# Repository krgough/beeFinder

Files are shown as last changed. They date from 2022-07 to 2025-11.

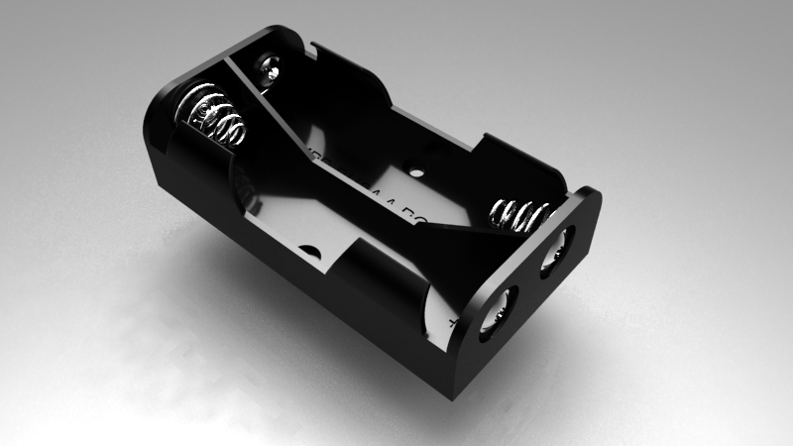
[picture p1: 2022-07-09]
docs/aa-battery-holder-2.snapshot.6/Renderings/aa holder.jpg

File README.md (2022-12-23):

# beeFinder

This device consists of:
- An array of 5x5 LEDs used as a display
- An RFM69HW 868MHz radio
- Arduino Pro Mini used as the controller

We have 2 modes of operation:
1) Display Name of Owner - Name scrolls from left to right.
2) Transmit a broadcast to other devices on 868MHz network.  Each column of LEDs is a user and the column leds correspond to the RSSI for that device.  The column for this device has only the lower LED lit

Mode selection is done using the SCAN/NAME switch.

# config.h
Create a config.h file with the radio encryption key.  This must be exactly 16 chars e.g.
```
#define ENCRYPTKEY    "sampleEncryptKey"
```

# vs-code
Install the arduino extension
Install arduino-cli
```
brew install arduino-cli
```
*** IMPORTANT: Restart vs-code

Use ```which arduino-cli``` to find the location of your executable
Set these vs-code settings...
arduino.path = <folder from 'which arduino-cli'>
arduino.command_path = arduino-cli

Set the script name in ardiono.json  

Typical arduino.json:
```
{
    "port": "/dev/tty.usbserial-AQ034BWC",
    "configuration": "cpu=16MHzatmega328",
    "board": "arduino:avr:pro",
    "sketch": "bee_finder_firmware/bee_finder/bee_finder.ino"
}
```

# Programming
- Connect GND, Tx, Rx
- Connect RTS from FTDI cable to DTR on the beekeeper device to allow it to set programming mode

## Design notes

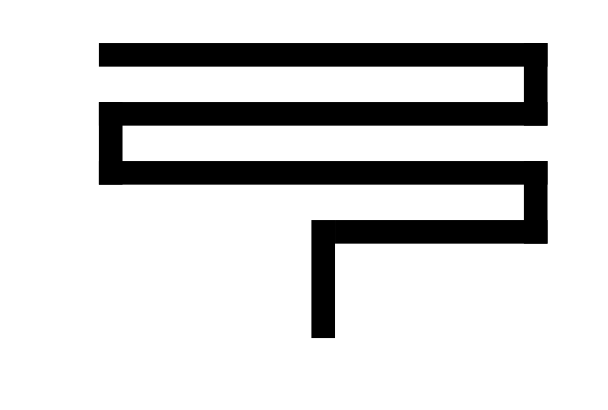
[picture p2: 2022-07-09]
docs/antenna/ti-868-antenna-meander.png

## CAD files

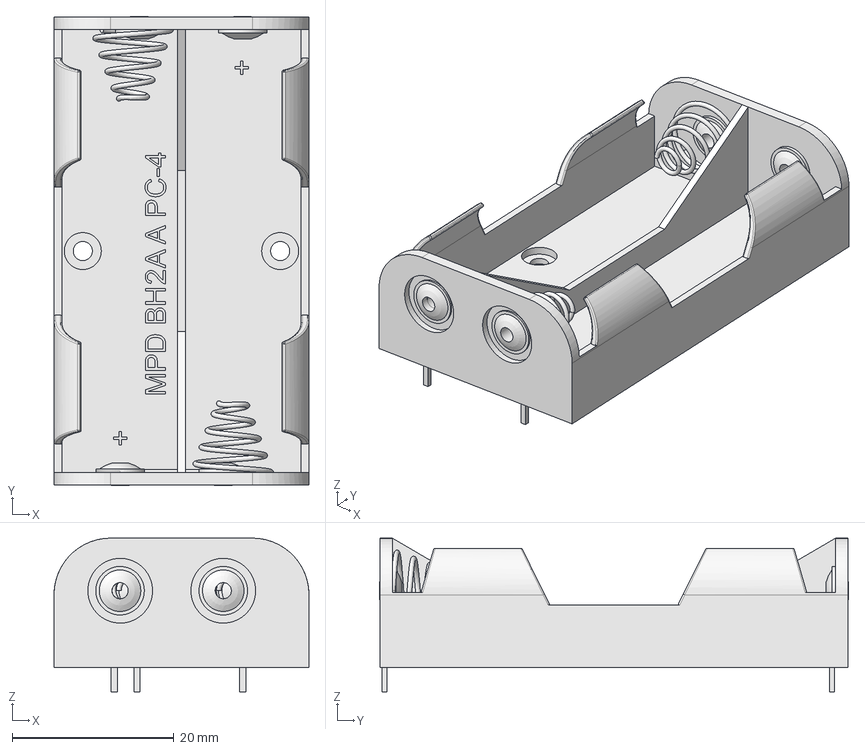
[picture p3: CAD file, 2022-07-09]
docs/aa-battery-holder-2.snapshot.6/aa_battery_box_pcb.step
31.5 x 58.0 x 19.0 mm

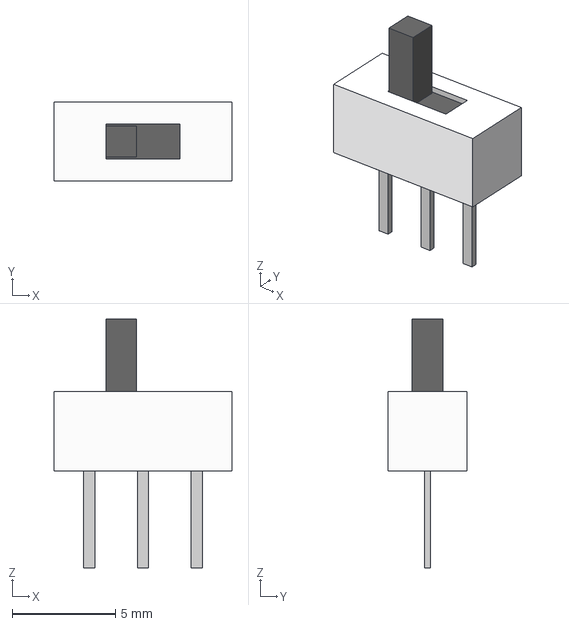
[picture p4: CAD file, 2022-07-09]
docs/Switch_SS12D00G4/SS12D00G4 1P2T Straight.step
8.61 x 3.85 x 12.1 mm

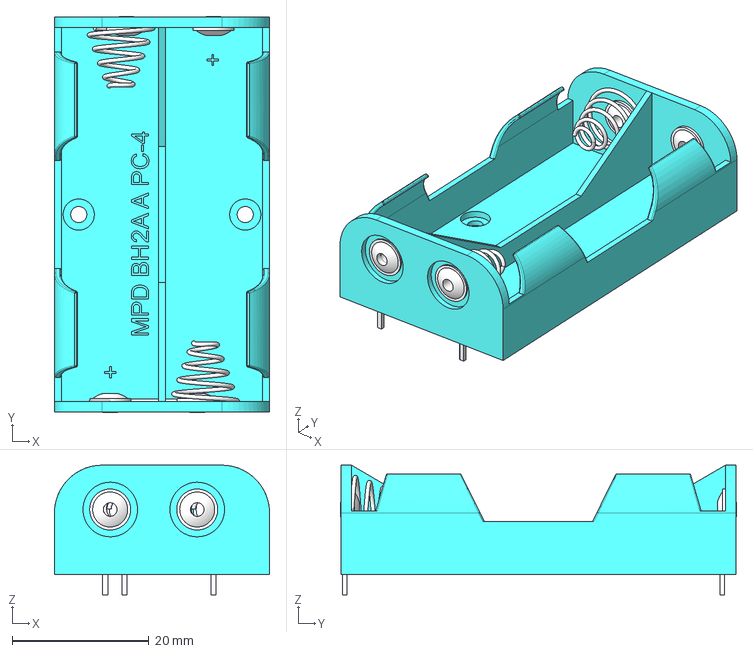
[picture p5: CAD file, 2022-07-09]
docs/aa-battery-holder-2.snapshot.6/AABattery Holder.stp
31.5 x 58.0 x 19.0 mm

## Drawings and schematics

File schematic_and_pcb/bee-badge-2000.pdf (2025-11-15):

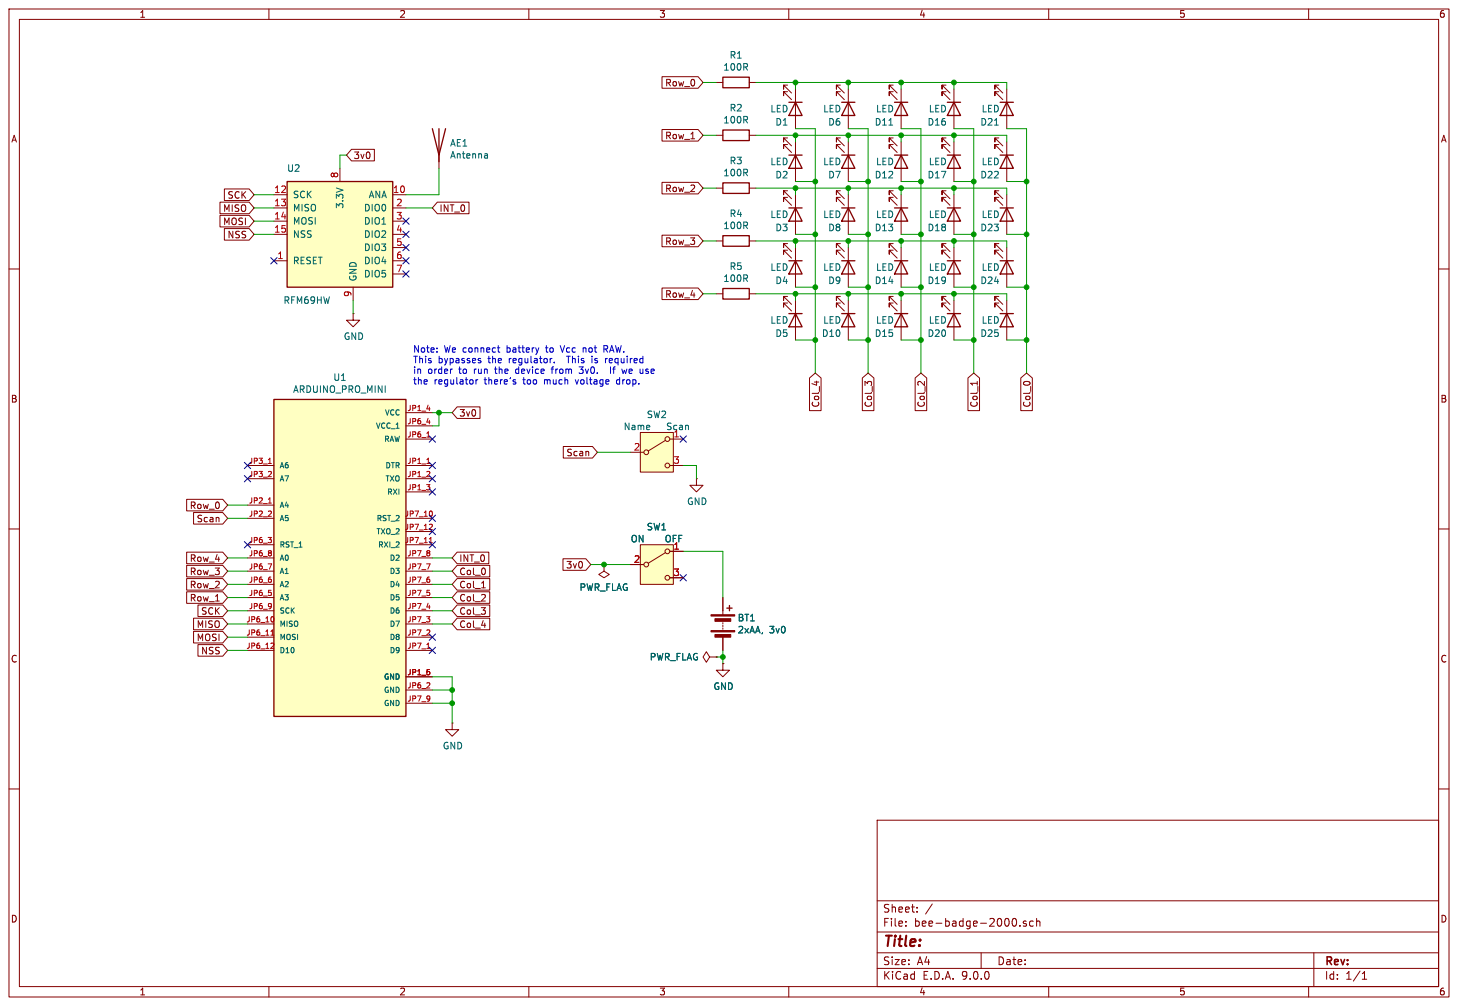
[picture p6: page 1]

Id: 1/1 Title: File: bee-badge-2000.sch Sheet: /

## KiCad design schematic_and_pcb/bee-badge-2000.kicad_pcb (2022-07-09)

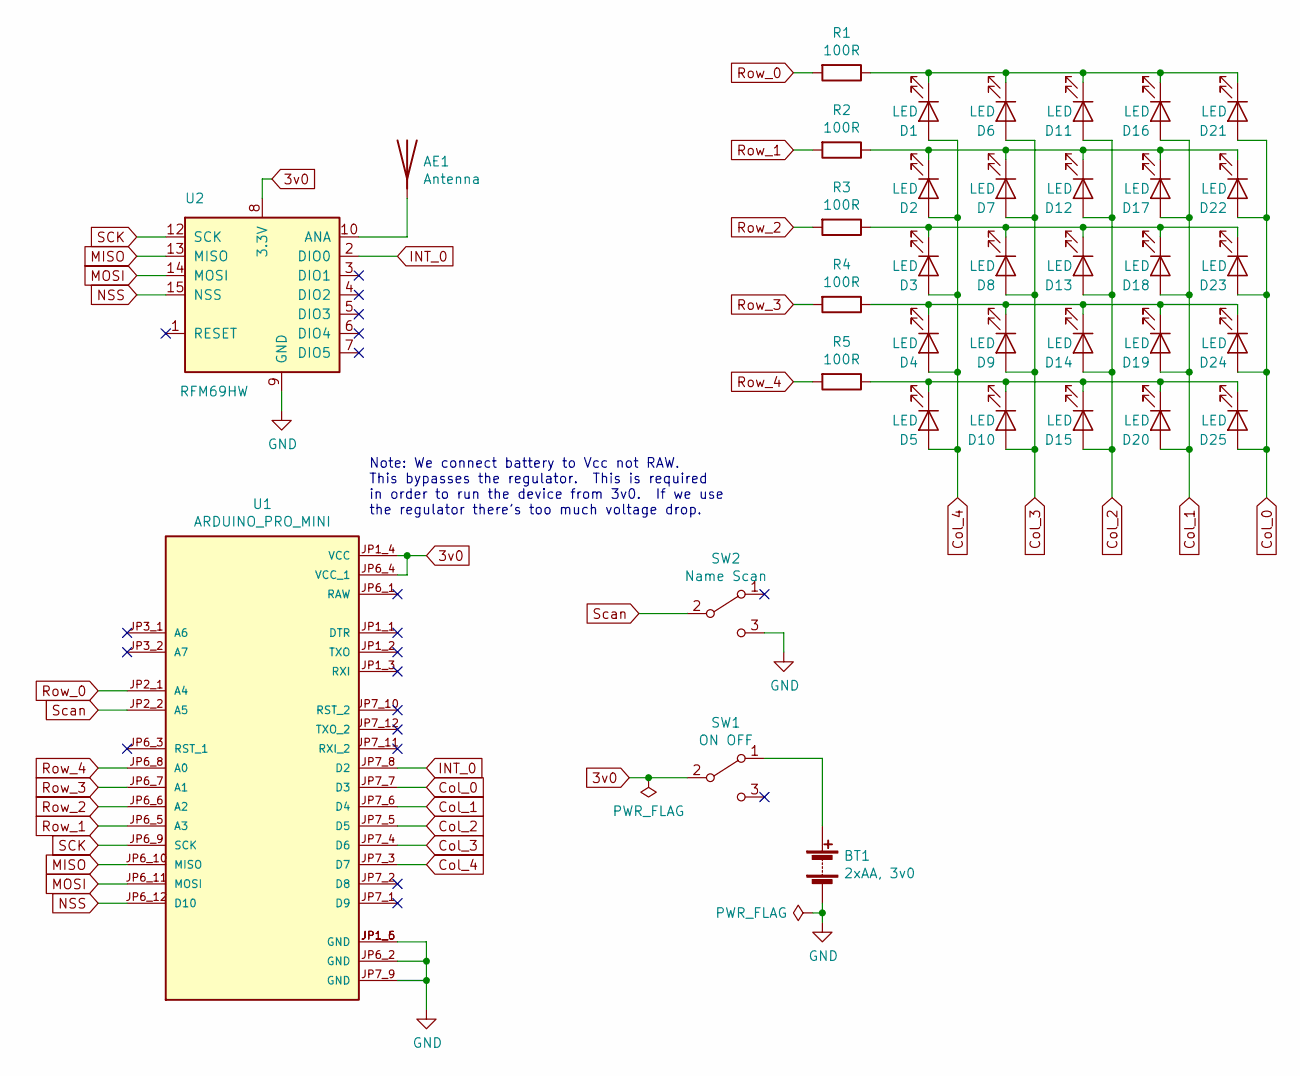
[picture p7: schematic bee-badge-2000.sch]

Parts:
AE1: Antenna; ti-868-antenna-meander
BT1: 2xAA, 3v0; 2xAA_Battery_Holder_PCB_Mount
D1, D2, D3, D4, D5, D6, D7, D8, D9, D10, D11, D12, D13, D14, D15, D16, D17, D18, D19, D20, D21, D22, D23, D24, D25: LED; LED_D5.0mm
R1, R2, R3, R4, R5: 100R; R_Axial_DIN0207_L6.3mm_D2.5mm_P10.16mm_Horizontal
SW1: ON OFF; SS12D00G4_spdt
SW2: Name Scan; SS12D00G4_spdt
U1: ARDUINO_PRO_MINI; MODULE_ARDUINO_PRO_MINI_CHINA; PARTREV N/A
U2: RFM69HW; HOPERF_RFM69HW

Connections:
3v0: SW1.2 (B), U1.JP1_4 (VCC), U1.JP6_4 (VCC_1), U2.8 (3.3V)
Col_0: D21.2 (A), D22.2 (A), D23.2 (A), D24.2 (A), D25.2 (A), U1.JP7_7 (D3)
Col_1: D16.2 (A), D17.2 (A), D18.2 (A), D19.2 (A), D20.2 (A), U1.JP7_6 (D4)
Col_2: D11.2 (A), D12.2 (A), D13.2 (A), D14.2 (A), D15.2 (A), U1.JP7_5 (D5)
Col_3: D6.2 (A), D7.2 (A), D8.2 (A), D9.2 (A), D10.2 (A), U1.JP7_4 (D6)
Col_4: D1.2 (A), D2.2 (A), D3.2 (A), D4.2 (A), D5.2 (A), U1.JP7_3 (D7)
GND: BT1.2 (-), SW2.3 (C), U1.JP1_5 (GND), U1.JP1_6 (GND), U1.JP6_2 (GND), U1.JP7_9 (GND), U2.9 (GND), U2.11 (GND)
INT_0: U1.JP7_8 (D2), U2.2 (DIO0)
MISO: U1.JP6_10 (MISO), U2.13 (MISO)
MOSI: U1.JP6_11 (MOSI), U2.14 (MOSI)
NSS: U1.JP6_12 (D10), U2.15 (NSS)
unnamed: AE1.1, U2.10 (ANA)
unnamed: BT1.1 (+), SW1.1 (A)
unnamed: D1.1 (K), D6.1 (K), D11.1 (K), D16.1 (K), D21.1 (K), R1.1
unnamed: D5.1 (K), D10.1 (K), D15.1 (K), D20.1 (K), D25.1 (K), R5.1
unnamed: D2.1 (K), D7.1 (K), D12.1 (K), D17.1 (K), D22.1 (K), R2.1
unnamed: D3.1 (K), D8.1 (K), D13.1 (K), D18.1 (K), D23.1 (K), R3.1
unnamed: D4.1 (K), D9.1 (K), D14.1 (K), D19.1 (K), D24.1 (K), R4.1
Row_0: R1.2, U1.JP2_1 (A4)
Row_1: R2.2, U1.JP6_5 (A3)
Row_2: R3.2, U1.JP6_6 (A2)
Row_3: R4.2, U1.JP6_7 (A1)
Row_4: R5.2, U1.JP6_8 (A0)
SCK: U1.JP6_9 (SCK), U2.12 (SCK)
Scan: SW2.2 (B), U1.JP2_2 (A5)

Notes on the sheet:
Note: We connect battery to Vcc not RAW. This bypasses the regulator. This is required in order to run the device from 3v0. If we use the regulator there’s too much voltage drop.

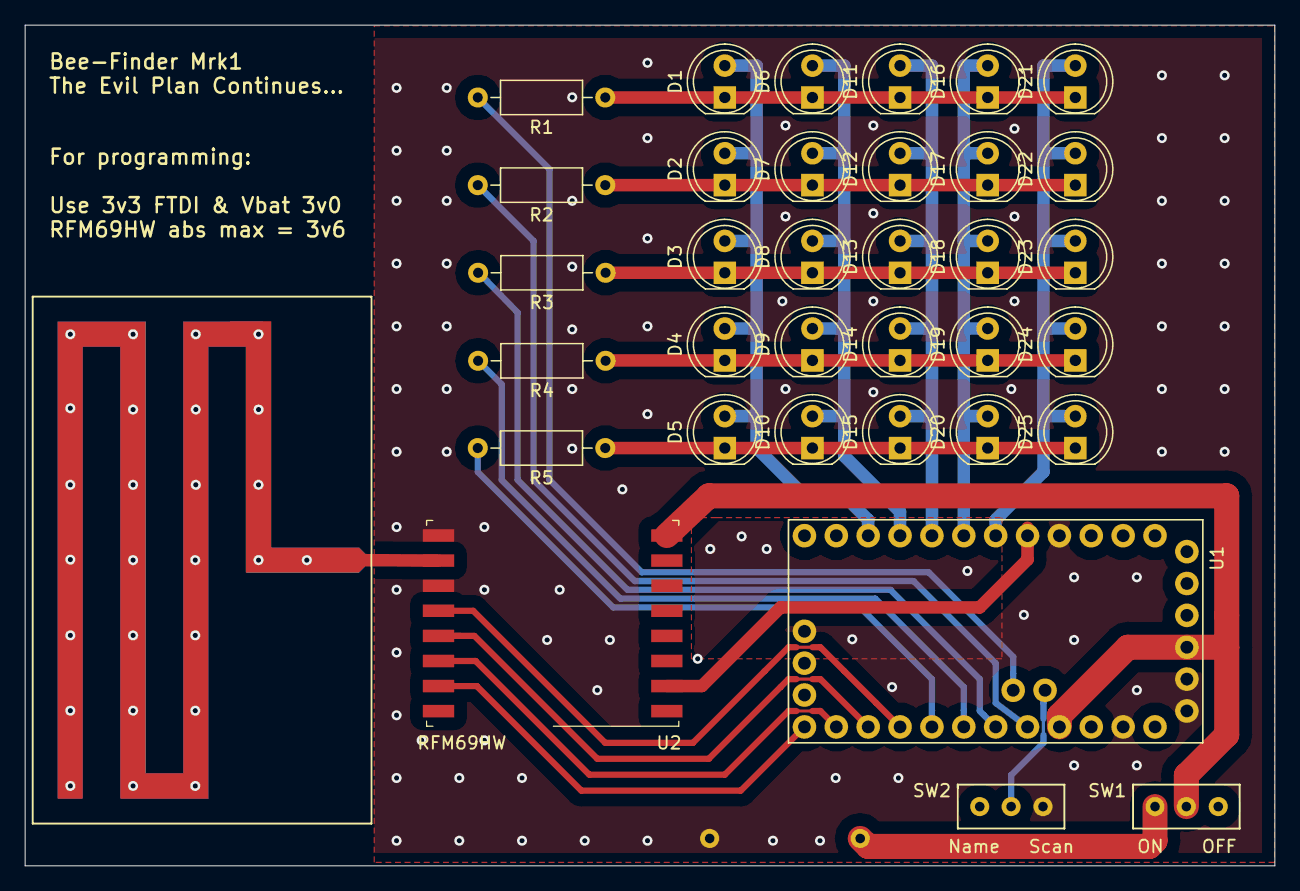
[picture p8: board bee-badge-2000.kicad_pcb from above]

Board: 2 copper layers, 99.6 x 67.0 mm, 36 parts (1 on the bottom side), 25 nets.

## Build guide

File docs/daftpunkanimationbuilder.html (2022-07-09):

Frame 1 of 1
Speed:

Overlay previous frame

Backup and Restore Tools

Generate code to save for later: native fmt | Restore from sequence code:

About the Daft Punk Animation Builder
This tool builds animation sequences for a Daft Punk display.

Click the grid to toggle the lights on/off.
< and > to navigate through frames.
Press > at the last frame to add a new frame.
<< and >> skip to beginning/end of sequence.
Insert and Delete add/remove frames.
Play animates the sequence in a loop.
Check Overlay to show the previous frame in blue. Helpful for animation.

To save an animation sequence to play on the Daft Punk Display click Generate, then copy the contents of the text box, and replace the contents of frames.h with it.
If you want to save a sequence for later editing instead, check native fmt and save it to a text file. You can resume editing it later via Restore frames

Restore frames from an existing sequence.
Paste the sequence code in the box and click Add.

-------------------------------------------------

This script was hacked from Ian's Project: Build your own internet graffiti wall
http://www.hackaday.com (http://hackaday.com/2008/10/02/how-to-networked-graffiti-wall/)

Thanks, Ian!

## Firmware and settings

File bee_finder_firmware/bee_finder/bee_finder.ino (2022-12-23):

// Bee-Finder Mrk1

// LED Rows and SCAN select are on PORTC
// -------------------------------------
// 
// PC0  PC1  PC2  PC3  PC4  PC5  PC6  PC7
// ADC0 ADC1 ADC2 ADC3 ADC4 ADC5 RST  xx
// |    |    |    |    |    |    |    |
// |    |    |    |    |    |    |    Unused
// |    |    |    |    |    |    Unused
// |    |    |    |    |    scan - Used for button input
// |<====== LEDs =====>| 
// 
// LED columns are on PORTD
// ------------------------
// PD7 PD6 PD5 PD4 PD3 PD2 PD1 PD0
// D07 D06 D05 D04 D03 D02 D01 D00
// |   |   |   |   |   |   |   |
// |   |   |   |   |   |   |   Rx 
// |   |   |   |   |   |   Tx
// |   |   |   |   |   Not used     
// |<=== LEDs ====>|   
//
// RFM69HW - Uses SPI plus an interrupt pin
// ----------------------------------------
// RFM69HW    ARDUINO Pins
// SCK  <---> D13 (PB5/SCK)
// MISO <---> D12 (PB4/MISO) 
// MOSI <---> D11 (PB3/MOSI)
// NSS  <---> D10 (PB2/SS - Slave Select)
// DIO  <---> D2 (PD2/INT0)
// 

#include "font.h"
#include <TimerOne.h>
#include "config.h"

// RFM69 Settings - using lowpowerlab library (see below)
// **********************************************************************************
#include <RFM69.h>         //get it here: https://www.github.com/lowpowerlab/rfm69
#include <RFM69_ATC.h>     //get it here: https://github.com/lowpowerlab/RFM69
#include <SPI.h>           //included with Arduino IDE (www.arduino.cc)
#include <LowPower.h>      //get library from: https://github.com/lowpowerlab/lowpower
#include <TimerOne.h>

//****************************************************************************************************************
//**** IMPORTANT RADIO SETTINGS - YOU MUST CHANGE/CONFIGURE TO MATCH YOUR HARDWARE TRANSCEIVER CONFIGURATION! ****
//****************************************************************************************************************
#define NETWORKID     19  //the same on all nodes that talk to each other.  Using 19 (from 19 Rathbone PLace)
//Match frequency to the hardware version of the radio on your Moteino (uncomment one):
//#define FREQUENCY     RF69_433MHZ
#define FREQUENCY     RF69_868MHZ
//#define FREQUENCY     RF69_915MHZ
// ENCRYPT key should be defined in config.h which is NOT in github
//#define ENCRYPTKEY    "sampleEncryptKey" //exactly the same 16 characters/bytes on all nodes!

#define IS_RFM69HW_HCW  //uncomment only for RFM69HW/HCW! Leave out if you have RFM69W/CW!
//*********************************************************************************************
//#define ENABLE_ATC      //comment out this line to disable AUTO TRANSMISSION CONTROL
#define ATC_RSSI        -75
//*********************************************************************************************

#ifdef ENABLE_ATC
  RFM69_ATC radio;
#else
  RFM69 radio;
#endif

// ***********************************************************************************************
// **** SETTINGS HERE ARE CUSTIMISED FOR EACH DEVICE  ****
// **********************************************************************************************
const byte KUNAL_UID  = 0;   //unique IDs.  Allocated in order of start dates.
const byte KEITH_UID  = 1;
const byte DERYA_UID  = 2;
const byte MERRY_UID  = 3;
const byte NAJEEB_UID = 4;
const byte NODEID     = KEITH_UID;  //change to one of the above UIDs to personalise this board

// Name string to be displayed and it's length. Rememeber to add a space on the end to get
// it to scroll off the screen nicely.
const int STR_LEN = 16;
const char MY_STRING[] = "MERRY CHRISTMAS ";
// **********************************************************************************************

// **********************************************************************************************
// ***** Name Display Settings ****
// **********************************************************************************************

const int DIM = 5;
int COL_COUNT = 0;
int COL_IDX = 0;
unsigned long LAST_COL_INC = 0;
byte CURRENT_FRAME[5];
#define SCROLL_RATE 200 // Milliseconds between column scrolls


// *************************
// **** Common settings ****
// *************************

const long SERIAL_BAUD = 115200;
volatile bool UPDATE_DISPLAY = false;

// Needs to be volatile as ISR is modifying this
volatile byte ROW = 0;
volatile byte BITMASK = 0x01;

// These are the pins we use for the rows and columns
const uint8_t ROWS[] = {A4, A3, A2, A1, A0};
const uint8_t COLS[] = {PD3, PD4, PD5, PD6, PD7};
const uint8_t SCAN_PIN = A5;

unsigned long LAST_TX = 0;
int TX_INTERVAL = 5000;
int RX_TIMEOUT = 10000;
unsigned long RX_TIMES[5] = {10000, 10000, 10000, 10000, 10000};
int RSSI_LEVELS[5] = {-999, -999 , -999 ,-999, -999};
byte RSSI_DATA[5] = {B00001,B00000,B00000,B00000,B00000};

void setup() {
  Serial.begin(SERIAL_BAUD);
  radio.initialize(FREQUENCY, NODEID, NETWORKID);
#ifdef IS_RFM69HW_HCW
  radio.setHighPower(); //must include this only for RFM69HW/HCW!
#endif
  radio.encrypt(ENCRYPTKEY);
  
#ifdef ENABLE_ATC
  radio.enableAutoPower(ATC_RSSI);
#endif

  char buff[50];
  sprintf(buff, "\nListening on %d Mhz...", FREQUENCY==RF69_433MHZ ? 433 : FREQUENCY==RF69_868MHZ ? 868 : 915);
  Serial.println(buff);
  Serial.flush();

  // set the LED pins as outputs
  for (int i=0; i<DIM; i++){
    pinMode(COLS[i], OUTPUT);
    pinMode(ROWS[i], OUTPUT);
  }

  // Set all the rows HIGH (Turn the row off)
  for (int i=0; i<DIM; i++){
    digitalWrite(ROWS[i], HIGH);
  }

  // Illumintate each LED in turn 
  for (int r=0; r<5; r++){
    digitalWrite(ROWS[r], LOW);
    for (int c=0; c<5; c++){
      digitalWrite(COLS[c], HIGH);
      delay(40);
      digitalWrite(COLS[c], LOW);
    }
    digitalWrite(ROWS[r], HIGH);
  }

  // Setup the scan pin
  pinMode(SCAN_PIN, INPUT_PULLUP);

  // Setup the display interrupt
  // We illuminate one LED at a time.  Timer1 defines the on period.
  Timer1.initialize(200);  // microseconds between pixels
  Timer1.attachInterrupt(isr_display_update);

  // Work out how many columns we have in our message by adding up the char size
  // for each char in the string. Chars can be 4,5 or 6 columns wide
  for (int i=0; i<STR_LEN; i++){
    COL_COUNT += get_char_length(MY_STRING[i]);
  }

  buildFrame();
}

// ********************************
// **** Name Display Functions ****
// ********************************

void incrementColumn(){
  // From scrolling text we define each column of pixels as a single step
  // and we increment the column index to walk through the message
  if (++COL_IDX > COL_COUNT - 1){
    COL_IDX = 0;
  }
}

int get_char_idx(){ 
  // For any given column index we need to be able to find the character
  // in the string that the column is part of.  This is because we are
  // using column_idx as our overall index.
  int col_sum = 0;
  for (int c=0; c<STR_LEN; c++){
    col_sum += get_char_length(MY_STRING[c]);
    if (COL_IDX < col_sum){
      return c;
    }
  }
}

int get_char_start(int str_idx){
  // Return the column index for the start of the current character
  int c_start = 0;
  for (int i=0; i<str_idx; i++){
    c_start += get_char_length(MY_STRING[i]);
  }
  return c_start;
}

int get_char_lookup_index(int my_char){
    // Subtract 65 (ascii for A) to get index in lookup
    //   or 
    // if it is a space then return the index for that special case
    if (my_char == ' '){
        return 26;
    }
    return (int)my_char - 65;
}

int get_char_length(int my_char){
  // Get character length from lookup table
  return pgm_read_byte(letter_len + get_char_lookup_index(my_char));
}

byte get_row(int my_char, int row){
  // Get the wanted character for the LED pixel LUT
  // Get the row data for the given row
  // We must use pgm_read_byte to read a byte from an address in program memory
  // The data is stored as an array of arrays so we have to use this macro twice
  return pgm_read_byte( pgm_read_byte(&(letters[get_char_lookup_index(my_char)])) + row );
}

void update_rssi_pixels(){
  // Update the RSSI pixel data based on the recorded RSSI levels
  for (int n=0; n<DIM; n++){
     (RSSI_LEVELS[n] > -40)  ? bitSet(RSSI_DATA[0], n) : bitClear(RSSI_DATA[0], n);
     (RSSI_LEVELS[n] > -60)  ? bitSet(RSSI_DATA[1], n) : bitClear(RSSI_DATA[1], n);
     (RSSI_LEVELS[n] > -80)  ? bitSet(RSSI_DATA[2], n) : bitClear(RSSI_DATA[2], n);
     (RSSI_LEVELS[n] > -100) ? bitSet(RSSI_DATA[3], n) : bitClear(RSSI_DATA[3], n);
     (RSSI_LEVELS[n] > -120) ? bitSet(RSSI_DATA[4], n) : bitClear(RSSI_DATA[4], n);
  }  
}

void buildFrame(){
  // For scrolling text we define each frame as the scrolling frames
  // We increment the frame counter to scroll the text one column to the left
  // In order to build the 5 led row data we use use bit manipulation to
  // 'add' characters together and then shuffle the bits to the correct position
  // for the current frame index.

  // The screen starts blank and we shuffle columns left onto  the screen
  // The index is 'pointing' at the RHS column so we need the previous 4
  // columns plus the current column to build the disaply data.

  int str_idx = get_char_idx();
  int char_len = get_char_length(MY_STRING[str_idx]);

  for (int r=0; r<DIM; r++){
    int col_data = 0;
    // Put previous char in upper bits
    if (str_idx != 0){
      col_data = get_row(MY_STRING[str_idx - 1], r);
      col_data <<= char_len;
    }
  
    // Put current char in lower bits
    col_data |= get_row(MY_STRING[str_idx], r);
  
    // Bit shift to get the screen data into the lower bits
    col_data >>= char_len - COL_IDX + get_char_start(str_idx);
    CURRENT_FRAME[r] = col_data &= 0b11111;
  }
}

void display_data(byte * row_data){
  // Turn the row off
  digitalWrite(ROWS[ROW], HIGH);

  // Build a bitmask for the column data
  // Move the column bitmask one bit left every iteration
  // We are turning on one pixel (row,col) every timer interrupt
  // If we have shown the whole row (all columns) then increment
  // to the next row.  Reset row if we have shown all rows.

  BITMASK = BITMASK << 1;
  if (BITMASK > (0b1 << DIM - 1)) {
    BITMASK = 0x01;
    ROW++;
    if (ROW >= DIM) {
      ROW = 0;
    }
  }

  // Turn off the LED bits and leave others as they are
  PORTD &= B00000111;
  // Use a bitmask to select a single bit then left shift the
  // data because we are using the upper 5 output bits.
  PORTD |= (row_data[ROW] & BITMASK) << 3;
  digitalWrite(ROWS[ROW], LOW); // Turn on the row
}

void loop() {

  // We are in SCAN mode so search for other beebadges and display their RSSI 
  if (!digitalRead(SCAN_PIN)){ 
    // Transmit our beacon
    // This sum handles the millis rollover
    // Difference of unsigned long works for this
    // We Sync the transmit with the update of the column corresponding to 
    // this nodeid - I'm expecting the 
    if (((millis() - LAST_TX) > TX_INTERVAL) ){ //&& (ROW == 0) && (BITMASK == NODEID)) {
      radio.send(RF69_BROADCAST_ADDR, "", 1);
      LAST_TX = millis();
    }
  
    // Reset the saved RSSI for any device that has not been heard recently
    for (int i=0; i<5; i++){
      if ((millis() - RX_TIMES[i]) > RX_TIMEOUT){
        (i == NODEID) ? RSSI_LEVELS[i] = -100 : RSSI_LEVELS[i] = -999;
      } 
    }
  
    if (radio.receiveDone())
    {
        RSSI_LEVELS[radio.SENDERID] = radio.RSSI;
        RX_TIMES[radio.SENDERID] = millis();
        //update_rssi_pixels();
    }
  
    if (UPDATE_DISPLAY){
      update_rssi_pixels();
      UPDATE_DISPLAY = false;
      display_data(RSSI_DATA);
    }
  }

  // We are in Name display mode
  else {
    if ((millis() - LAST_COL_INC) > SCROLL_RATE) {
      LAST_COL_INC = millis();
      incrementColumn();
      buildFrame();
//      for (int i=0; i<DIM; i++){
//        Serial.println(CURRENT_FRAME[i],BIN);
//      }
    }
    if (UPDATE_DISPLAY){
      UPDATE_DISPLAY = false;
      display_data(CURRENT_FRAME);
    }
  }
  
}

void isr_display_update(){
  UPDATE_DISPLAY = true;
}

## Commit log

2022-12-23 Fixed frequency of arduino clock
    [bee_finder.ino]
2025-11-15 adding pdf of the schematic
